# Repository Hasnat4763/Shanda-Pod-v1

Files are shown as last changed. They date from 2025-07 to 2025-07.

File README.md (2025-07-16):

# Shanda Pod

It is an MP3 player which can also play audio via bluetooth A2DP source and a PCM5102A module

I made this project because I wanted to experiment with mp3 players and I need an mp3 player with bluetooth outputs

# PCB

This is the Schematic



This is the PCB



PCB 3D View





# CAD

I designed it in Fusion360 which was pretty hard as it crashed idk why
This is all the parts fitted together







This is a cover which will sit on top of the battery



# Schematic

I have some parts outside of my PCB



# BOM

| Name | Qty | Final Price - USD(BDT) | Link |
| --- | --- | --- | --- |
| ESP-32-WROVER-E | 1 | US $7.39 | [here](https://www.aliexpress.com/item/1005008347478258.html?spm=a2g0o.cart.0.0.35b638daQUHsS4&mp=1) |
| NASAYI 10pcs/lot DM3AT-SF-PEJM5 | 10  | US $8.63 | [here](https://www.aliexpress.com/item/1005009250329013.html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) |
| CH340C sop-16 Chipset | 5 | US $1.44 | [here](https://www.aliexpress.com/item/1005004970840775.html?spm=a2g0o.cart.0.0.35b638daQUHsS4&mp=1) |
| 6092 bq25185 USB / DC / Solar Charger with 3.3V Buck Board | 1 | US $13.66 | [here](https://www.aliexpress.com/item/1005008651296534.html?spm=a2g0o.cart.0.0.35b638daQUHsS4&mp=1) |
| 100NF 0.1UF 50V C0805 Capacitor | 100 | US $0.73 | [here](https://www.aliexpress.com/item/1115774532.html?spm=a2g0o.cart.0.0.35b638daQUHsS4&mp=1) |
|  SSD1306 | 1 | US $1.42 | [here](https://www.aliexpress.com/item/1005003780343300.html?spm=a2g0o.cart.0.0.35b638daQUHsS4&mp=1) |
| PCM5102A DAC | 1 | US $4.05 | [here](https://www.aliexpress.com/item/1005006104368969.html?spm=a2g0o.cart.0.0.35b638daQUHsS4&mp=1) |
| Insert M1.6 Brass Heat Threaded Insert Nut and Stainless Steel Screw  |set  | US $15.02 | [here](https://www.aliexpress.com/item/1005004837433548.html?spm=a2g0o.cart.0.0.35b638daQUHsS4&mp=1) |
| MHP30 Mini Hot Plate | 1 | US $13.52 | [here](https://www.aliexpress.com/item/1005005887052045.html?spm=a2g0o.cart.0.0.72f938daHYVVmK&mp=1) |
| 18650 Lithium-ion | 2 | 348 BDT | [here](https://www.daraz.com.bd//products/i337388376-s1645620986.html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) |
| PCB | 5 | US $26.68 | [here](https://hc-cdn.hel1.your-objectstorage.com/s/v3/ba1be02d5d65575ba7409b266db8009ed1d59e8f_image.png) |
| Stencil | 1 | US $$8.90 | [here](https://hc-cdn.hel1.your-objectstorage.com/s/v3/ba1be02d5d65575ba7409b266db8009ed1d59e8f_image.png) | |
| Soldering Paste | 1 | US $3.81 | [here](https://www.aliexpress.com/item/1005009298760047.html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) | 
| Top Case | 1 | Printing Legion | 
| Bottom Case | 1 | Printing Legion |
| Battery Cover | 1 | Printing Legion |

# Total Cost: ~ 115$ USD

# Why is this too exbensive?

Check this out



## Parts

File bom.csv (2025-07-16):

Name | Qty | Final Price - USD(BDT) | Link
ESP-32-WROVER-E | 1 | US $7.39 | https://www.aliexpress.com/item/1005008347478258.html?spm=a2g0o.cart.0.0.35b638daQUHsS4&mp=1
NASAYI 10pcs/lot DM3AT-SF-PEJM5 | 10 | US $8.63 | https://www.aliexpress.com/item/1005009250329013.html?spm=a2g0o.cart.0.0.35b638daQUHsS4&mp=1
CH340C sop-16 Chipset | 5 | US $1.44 | https://www.aliexpress.com/item/1005004970840775.html?spm=a2g0o.cart.0.0.35b638daQUHsS4&mp=1
6092 bq25185 USB / DC / Solar Charger with 3.3V Buck Board | 1 | US $13.66 | https://www.aliexpress.com/item/1005008651296534.html?spm=a2g0o.cart.0.0.35b638daQUHsS4&mp=1
100NF 0.1UF 50V C0805 Capacitor | 100 | US $0.73 | https://www.aliexpress.com/item/1115774532.html?spm=a2g0o.cart.0.0.35b638daQUHsS4&mp=1
SSD1306 | 1 | US $1.42 | https://www.aliexpress.com/item/1005003780343300.html?spm=a2g0o.cart.0.0.35b638daQUHsS4&mp=1
PCM5102A DAC | 1 | US $4.05 | https://www.aliexpress.com/item/1005006104368969.html?spm=a2g0o.cart.0.0.35b638daQUHsS4&mp=1
Insert M1.6 Brass Heat Threaded Insert Nut and Stainless Steel Screw | set | US $15.02 | https://www.aliexpress.com/item/1005004837433548.html?spm=a2g0o.cart.0.0.35b638daQUHsS4&mp=1
MHP30 Mini Hot Plate | 1 | US $13.52 | https://www.aliexpress.com/item/1005005887052045.html?spm=a2g0o.cart.0.0.72f938daHYVVmK&mp=1
18650 Lithium-ion | 2 | 348 BDT | https://www.daraz.com.bd//products/i337388376-s1645620986.html?spm=a2o42.cart.0.0.5b8f282903B5mN
PCB | 5 | US $26.68 | https://hc-cdn.hel1.your-objectstorage.com/s/v3/ba1be02d5d65575ba7409b266db8009ed1d59e8f_image.png
Stencil | 1 | US $8.90 | https://hc-cdn.hel1.your-objectstorage.com/s/v3/ba1be02d5d65575ba7409b266db8009ed1d59e8f_image.png
Soldering Paste | 1 | US $5.66 | https://www.aliexpress.com/item/1005006866665560.html?spm=a2g0o.productlist.main.1.6cdaixN5ixN5lS
Top Case | 1 | Printing Legion
Bottom Case | 1 | Printing Legion
Battery Cover | 1 | Printing Legion
Total Cost |  | US $115.00

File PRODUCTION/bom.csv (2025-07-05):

Designator | Footprint | Quantity | Value | LCSC Part #
C1, C2, C3, C4 | 0805 | 4 | 0.1uF
J1 | microSD_HC_Hirose_DM3AT-SF-PEJM5 | 1 | Micro_SD_Card_Det2
J2 | MODULE_DM-OLED096-636 | 1 | Conn_01x04_Pin
J3 | PinHeader_1x04_P1.27mm_Vertical | 1 | Conn_01x04_Pin
J5 | PinHeader_1x05_P1.00mm_Horizontal | 1 | Conn_01x05_Socket
S1, S2, S3, S4, S5, S6 | SW_FSM8JH | 6 | FSM8JH
U1 | ESP32-WROVER-E | 1 | ESP32-WROVER-E
U3 | SOIC127P600X180-16N | 1 | CH340C

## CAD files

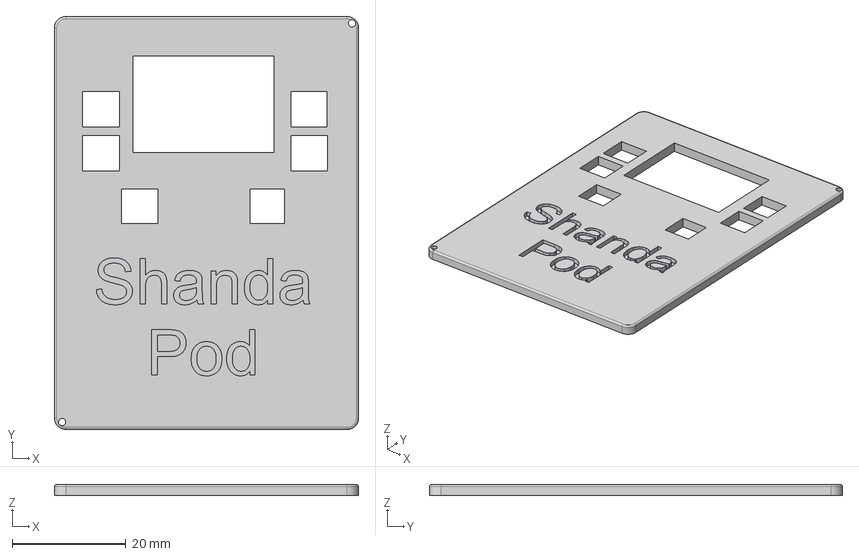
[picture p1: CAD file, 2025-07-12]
CAD/Shanda Pod Top.step
53.4 x 72.5 x 2.00 mm

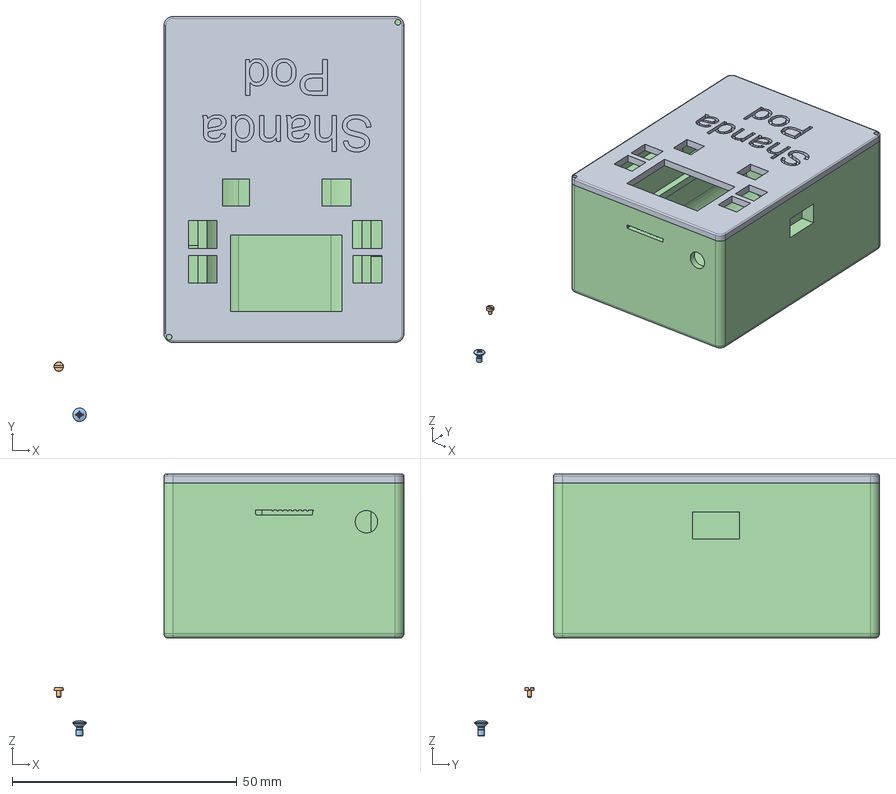
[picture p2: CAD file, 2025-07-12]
CAD/Shanda Pod Bottom.step
77.8 x 90.1 x 58.2 mm
SCHMS BS 4183 - M1 x 1.5 Steel 4.6 Plain
ČSN EN ISO 7047 - M1.6x3 - Z Steel 4.6 Plai n

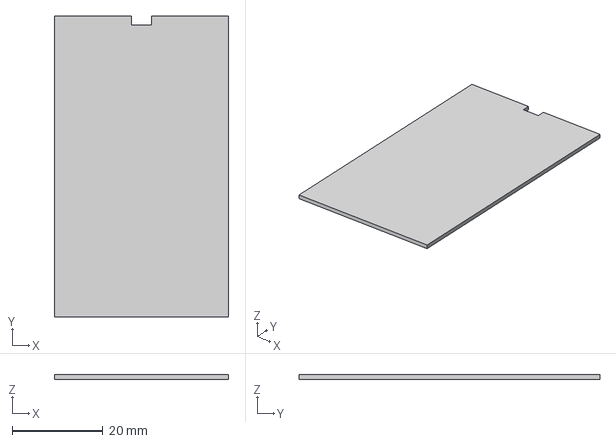
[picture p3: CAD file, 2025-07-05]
CAD/Shanda Pod Battery Cover.step
38.5 x 66.5 x 1.00 mm

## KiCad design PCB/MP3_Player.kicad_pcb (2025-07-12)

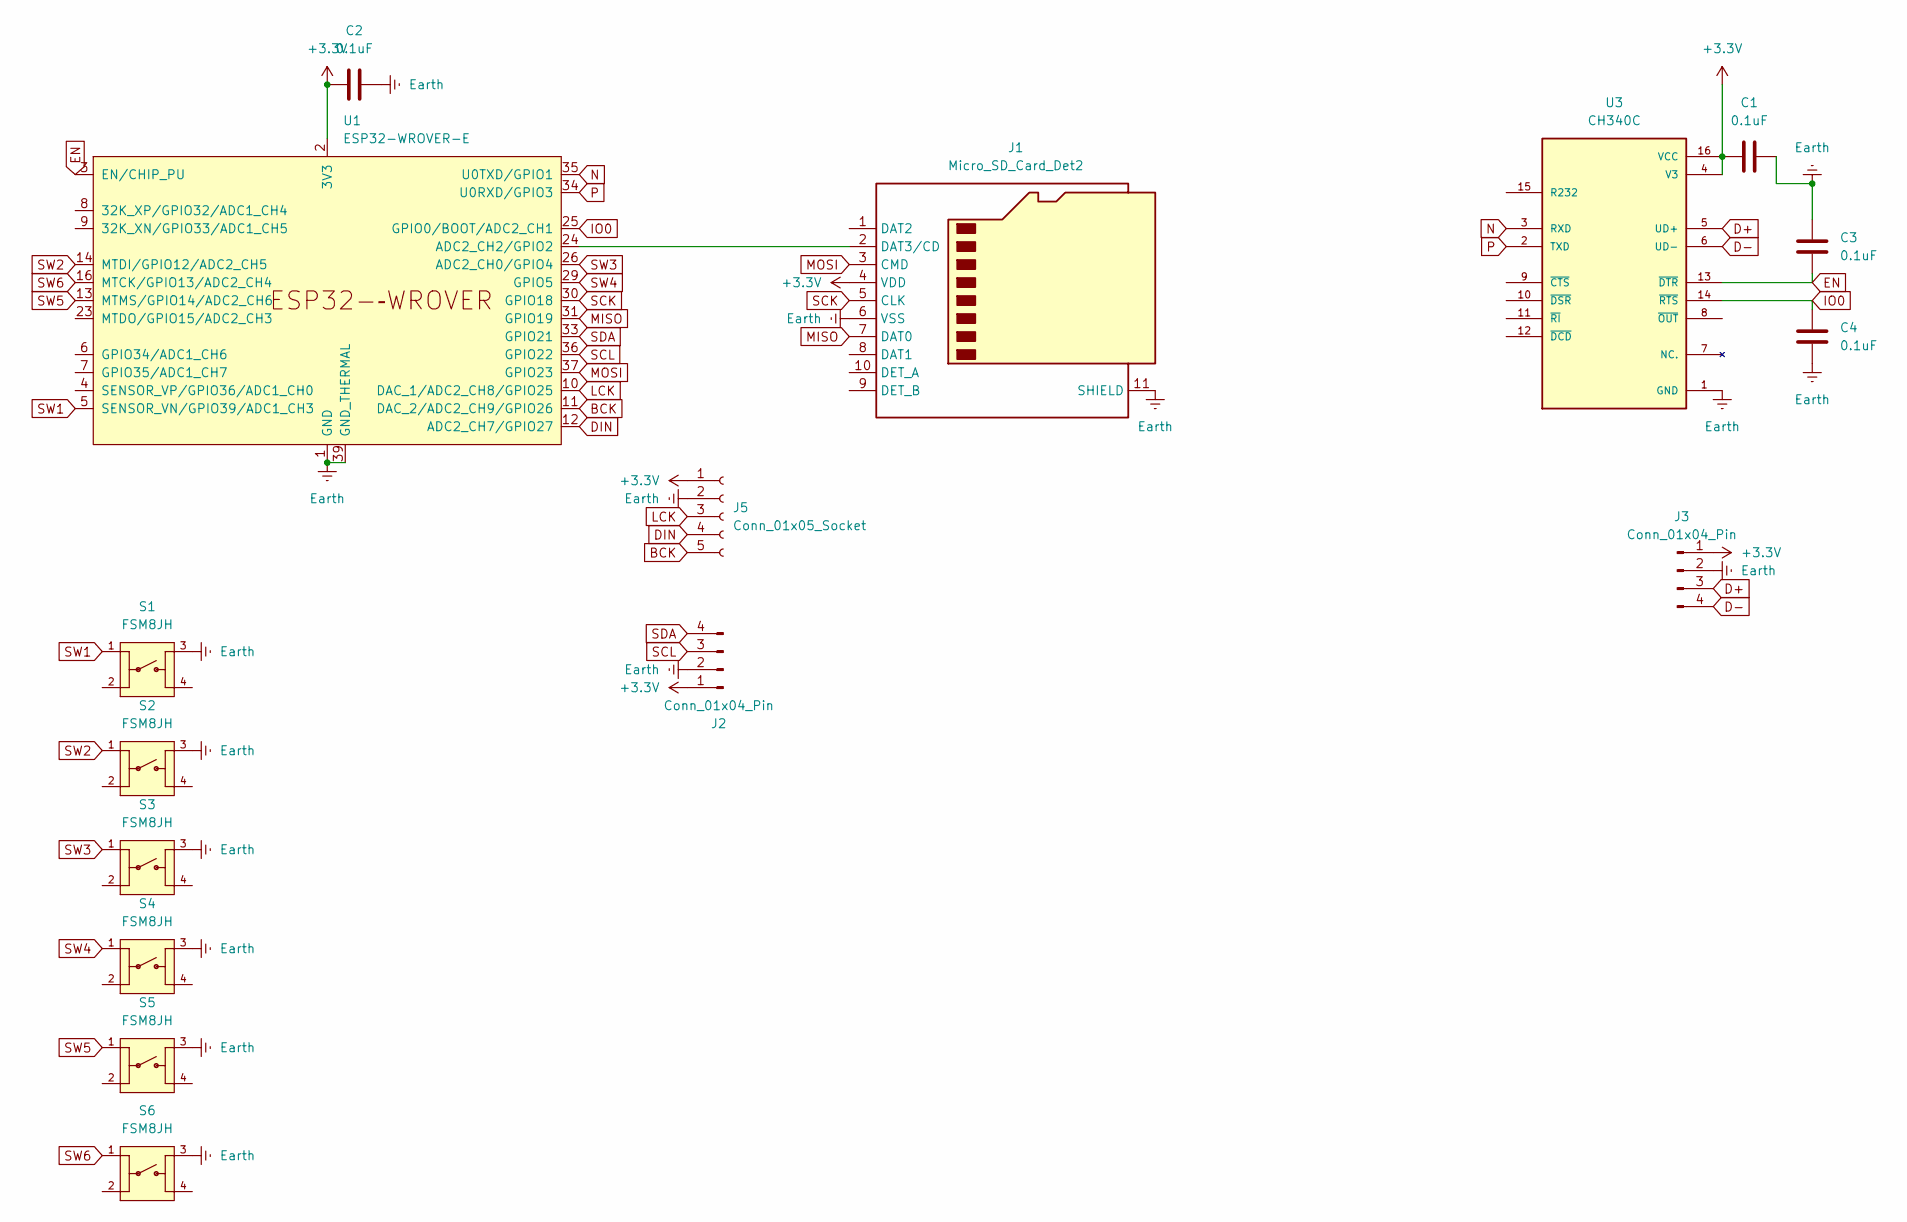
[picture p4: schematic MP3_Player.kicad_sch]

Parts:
C1, C2, C3, C4: 0.1uF; C_0805_2012Metric
J1: Micro_SD_Card_Det2; microSD_HC_Hirose_DM3AT-SF-PEJM5
J2: Conn_01x04_Pin; MODULE_DM-OLED096-636
J3: Conn_01x04_Pin; PinHeader_1x04_P1.27mm_Vertical
J5: Conn_01x05_Socket; PinHeader_1x05_P1.00mm_Horizontal
S1, S2, S3, S4, S5, S6: FSM8JH; SW_FSM8JH; PARTREV C10
U1: ESP32-WROVER-E
U3: CH340C; SOIC127P600X180-16N; PARTREV 2G

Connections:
+3.3V: C1.1, C2.1, J1.4 (VDD), J2.1, J3.1, J5.1, U1.2 (3V3), U3.4 (V3), U3.16 (VCC)
BCK: J5.5, U1.11 (DAC_2/ADC2_CH9/GPIO26)
D+: J3.3, U3.5 (UD+)
D-: J3.4, U3.6 (UD-)
DIN: J5.4, U1.12 (ADC2_CH7/GPIO27)
EN: C3.1, U1.3 (EN/CHIP_PU), U3.13 (~DTR)
Earth: C1.2, C2.2, C3.2, C4.1, J1.6 (VSS), J1.11 (SHIELD), J2.2, J3.2, J5.2, S1.3, S2.3, S3.3, S4.3, S5.3, S6.3, U1.1 (GND), U1.15 (GND), U1.38 (GND), U1.39 (GND_THERMAL), U3.1 (GND)
IO0: C4.2, U1.25 (GPIO0/BOOT/ADC2_CH1), U3.14 (~RTS)
LCK: J5.3, U1.10 (DAC_1/ADC2_CH8/GPIO25)
MISO: J1.7 (DAT0), U1.31 (GPIO19)
MOSI: J1.3 (CMD), U1.37 (GPIO23)
N: U1.35 (U0TXD/GPIO1), U3.3 (RXD)
unnamed: J1.2 (DAT3/CD), U1.24 (ADC2_CH2/GPIO2)
P: U1.34 (U0RXD/GPIO3), U3.2 (TXD)
SCK: J1.5 (CLK), U1.30 (GPIO18)
SCL: J2.3, U1.36 (GPIO22)
SDA: J2.4, U1.33 (GPIO21)
SW1: S1.1, U1.5 (SENSOR_VN/GPIO39/ADC1_CH3)
SW2: S2.1, U1.14 (MTDI/GPIO12/ADC2_CH5)
SW3: S3.1, U1.26 (ADC2_CH0/GPIO4)
SW4: S4.1, U1.29 (GPIO5)
SW5: S5.1, U1.13 (MTMS/GPIO14/ADC2_CH6)
SW6: S6.1, U1.16 (MTCK/GPIO13/ADC2_CH4)

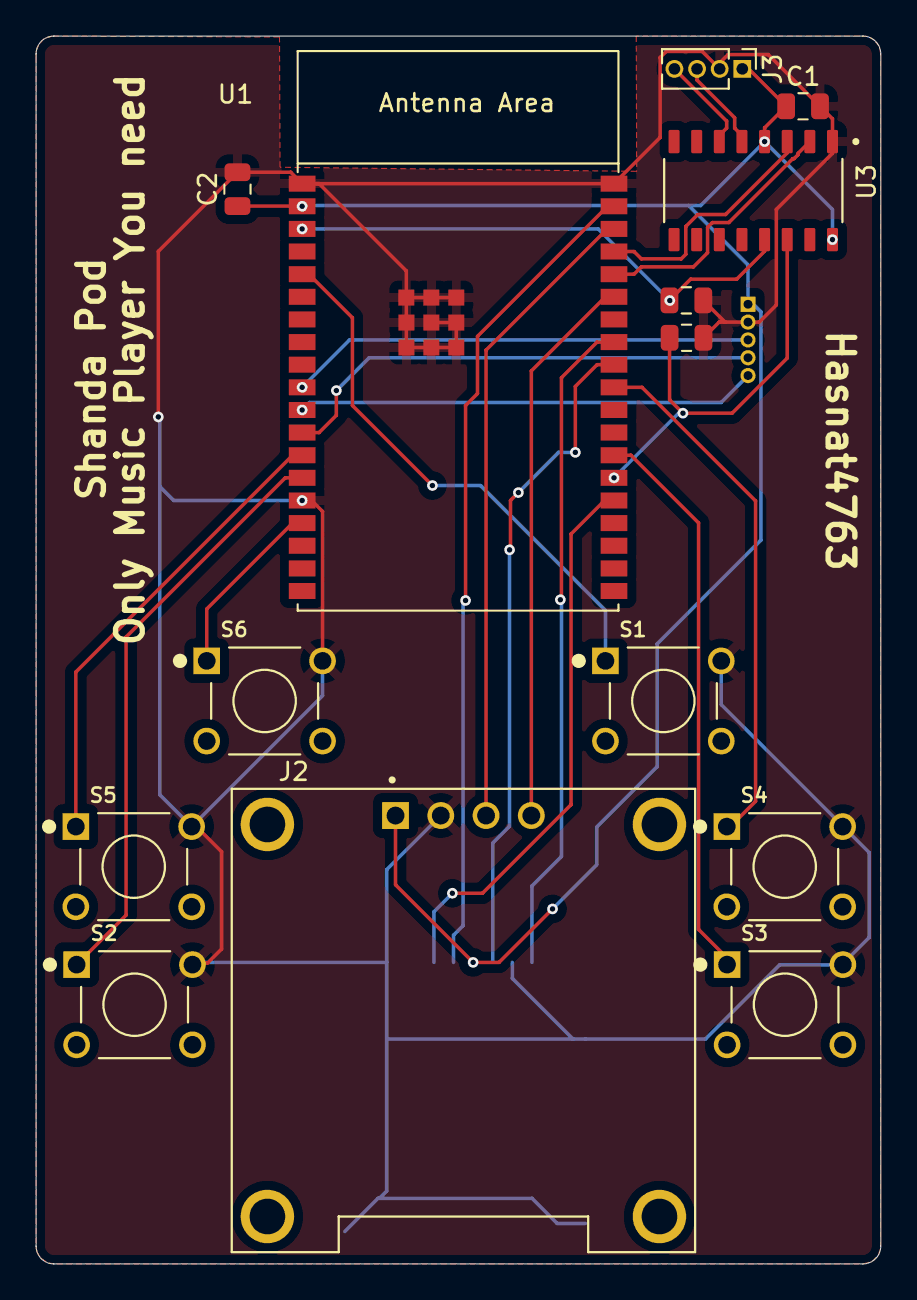
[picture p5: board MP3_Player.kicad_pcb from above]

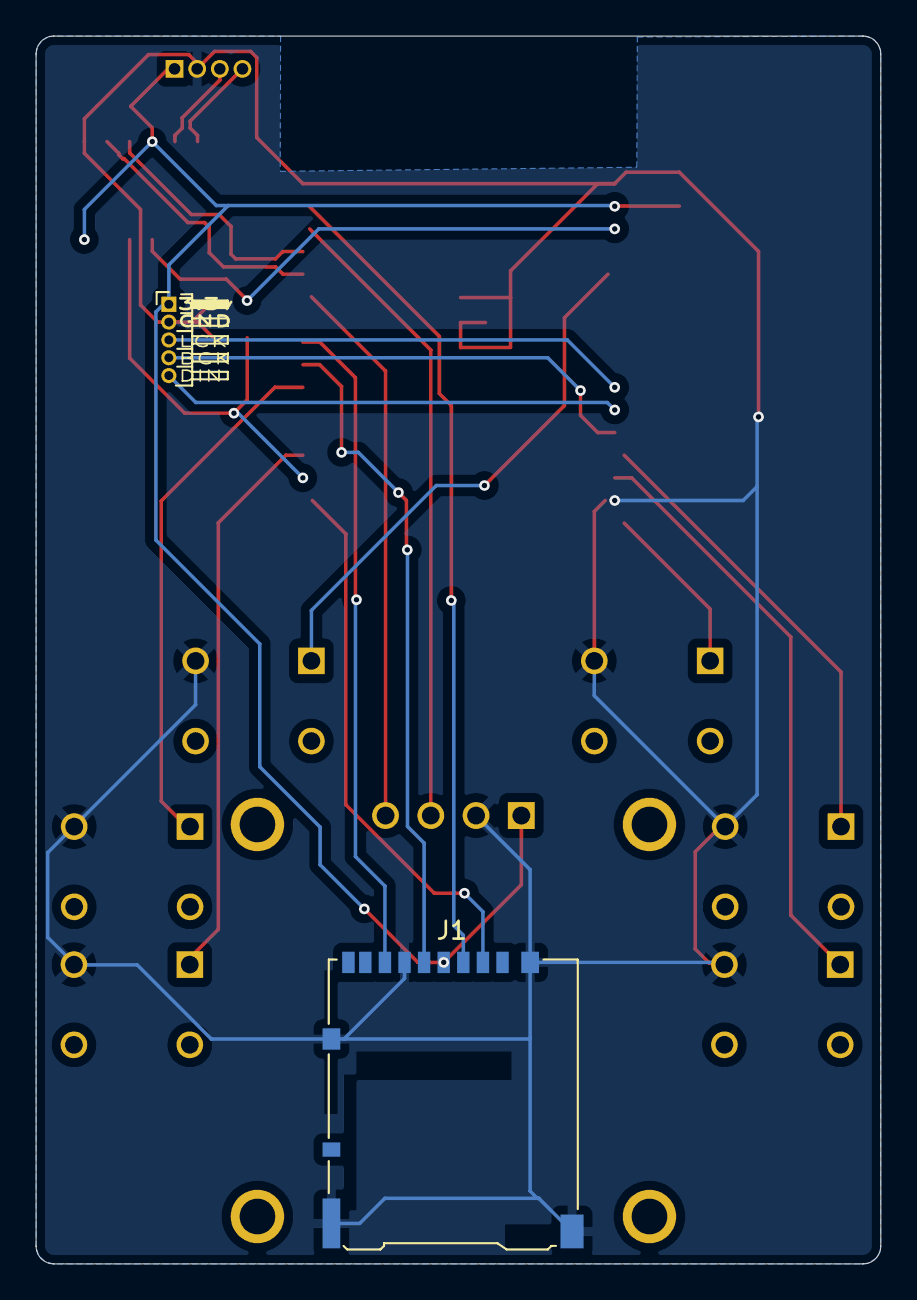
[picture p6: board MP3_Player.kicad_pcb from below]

Board: 2 copper layers, 47.4 x 68.9 mm, 16 parts (2 on the bottom side), 23 nets.

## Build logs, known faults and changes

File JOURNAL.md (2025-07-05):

---
title: "Shanda Pod"
author: "Hasnat"
description: "It is an MP3 player!"
created_at: "2025-06-05"
---

# Total Time Spent: 20.5h

# June 5th: Started Making the base

I have started working on an MP3 player which will also be able to output audio to my Airbuds.

I have selected the ESP32 WROVER as the MCU.

Put an OLED display and SD card reader to it too.





Not sure about them tho still a lot to do

**Total time spent: 3hr**

# June 8th: Edited the schematic a bit

I never used a microSD card with any microcontroller before so I was confused as how to wire the pins to my ESP32. I finally figured it out and wired them up. I also added 4 male jumper pins so that I can easily use a USB to 

TTL converter or my arduino nano to flash new codes on the ESP32.





PCB looks like this now

**Total time spent: 1hr**

# June 9th: Added voltage converter

The ESP32 runs on 3.3v but most of the batteries we find like the 18650 li-ion batteries all have a voltage range of 3.7-4.2 which is not safe for the ESP32 so I desided to include a AMS1117 LDO to limit the voltage to 3.3v. I also put a JST connector to connect the battery to the PCB.





**Total time spent: 2hr**

# June 11th: Added extra switch and tidied up the schematic

Thought I need some more switches for the MP3 player. So added 2 more switches.

Gonna start working on the case now.





**Total time spent: 0.5hr**

# June 13th: Changed switch model and added voltage reading

I want to also see how much charge is left on the battery, so I added 2 resistors to step down the voltage which esp32 can read safely
Also Changed the switch models







**Total time spent: 0.5hr**

# June 18th: Finalizing the case

Got some free time today to become Good in CAD. I still have to figure out where to put the battery tho





**Total time spent: 1.5hr**

# June 20th: Big Changes

I have decided to also include a GY-PCM5102 module for audio output so I have to change many things. I have also changed the case design to be more compact
Placed the Charging and Audio out Module till now
Have to put the power button now

Also Changed the PCB





**Total time spent: 2hr**

# June 21th: Big Changes

Changed the Battery Charging module for an adafruit bq25185 charging module as it has both charging and 3v3 output. Removed AMS1117 and battery percentage function from the PCB
Made space for the new module in Case.





**Total time spent: 2.5hr**

# June 23th: WHY AM I DOING THIS?

I have exams tomorrow and yet I am making the case
I completed the case (Looks Like I am gonna change it again ngl) and made an exploding animation of it!

https://github.com/user-attachments/assets/a201ade8-0bba-4978-ab63-54ee87a1c3f5

**Total time spent: 1.5hr**

# June 26th: Adding CH340C

Thought of including an CH340C USB to UART converter to upload codes easily and also my battery charger also exposes D+ D- so it is easier than ever







**Total time spent: 2hr**

# June 27th: Completely changing the case design and choosing battery

I had completely redone the case and selected 2 18650 batteries to power it and added a rocker switch to turn on/off

(Hope everything fits)



**Total time spent: 3hr**

# July 1st: Adding screw holes and switch

I made holes for 2 M1.6 screws and made hole for a slide switch




**Total time spent: 1hr**

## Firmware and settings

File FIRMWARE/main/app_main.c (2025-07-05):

#include <stdio.h>
#include <dirent.h>
#include <string.h>
#include "freertos/FreeRTOS.h"
#include "freertos/task.h"
#include "driver/gpio.h"
#include "esp_log.h"
#include "esp_err.h"
#include "audio_element.h"
#include "audio_pipeline.h"
#include "audio_event_iface.h"
#include "esp_vfs_fat.h"
#include "sdmmc_cmd.h"
#include "i2s_stream.h"
#include "fatfs_stream.h"
#include "mp3_decoder.h"
#include "esp_peripherals.h"
#include "periph_sdcard.h"
#include "board.h"

static const char *TAG = "MP3_PLAYER";

#define MOUNT_POINT "/sdcard"


#define BUTTON_NEXT        GPIO_NUM_32
#define BUTTON_PREV        GPIO_NUM_33
#define BUTTON_PLAY_PAUSE  GPIO_NUM_25
#define BUTTON_VOL_UP      GPIO_NUM_26
#define BUTTON_VOL_DOWN    GPIO_NUM_27
#define BUTTON_BL_CONTROL  GPIO_NUM_14

#define MAX_FILES 64
static char file_list[MAX_FILES][256];
static int total_files = 0;
static int current_index = 0;
static bool is_playing = true;
static audio_pipeline_handle_t pipeline = NULL;
static audio_element_handle_t i2s_stream_writer = NULL;

void play_file(const char *filepath)
{
    ESP_LOGI(TAG, "Playing file: %s", filepath);

    if (pipeline) {
        audio_pipeline_terminate(pipeline);
        audio_pipeline_deinit(pipeline);
        pipeline = NULL;
    }

    audio_element_handle_t fatfs_stream_reader, mp3_decoder;

    audio_pipeline_cfg_t pipeline_cfg = DEFAULT_AUDIO_PIPELINE_CONFIG();
    pipeline = audio_pipeline_init(&pipeline_cfg);
    mem_assert(pipeline);

    fatfs_stream_cfg_t fatfs_cfg = FATFS_STREAM_CFG_DEFAULT();
    fatfs_cfg.type = AUDIO_STREAM_READER;
    fatfs_stream_reader = fatfs_stream_init(&fatfs_cfg);

    mp3_decoder_cfg_t mp3_cfg = DEFAULT_MP3_DECODER_CONFIG();
    mp3_decoder = mp3_decoder_init(&mp3_cfg);

    i2s_stream_cfg_t i2s_cfg = I2S_STREAM_CFG_DEFAULT();
    i2s_cfg.type = AUDIO_STREAM_WRITER;
    i2s_stream_writer = i2s_stream_init(&i2s_cfg);

    audio_pipeline_register(pipeline, fatfs_stream_reader, "file");
    audio_pipeline_register(pipeline, mp3_decoder, "mp3");
    audio_pipeline_register(pipeline, i2s_stream_writer, "i2s");

    audio_pipeline_link(pipeline, (const char *[]) {"file", "mp3", "i2s"}, 3);

    audio_element_set_uri(fatfs_stream_reader, filepath);

    audio_pipeline_run(pipeline);
    is_playing = true;
}

void configure_buttons()
{
    gpio_config_t io_conf = {
        .intr_type = GPIO_INTR_DISABLE,
        .mode = GPIO_MODE_INPUT,
        .pull_up_en = GPIO_PULLUP_ENABLE,
        .pull_down_en = GPIO_PULLDOWN_DISABLE,
        .pin_bit_mask = (1ULL << BUTTON_NEXT) | (1ULL << BUTTON_PREV) |
                        (1ULL << BUTTON_PLAY_PAUSE) | (1ULL << BUTTON_VOL_UP) |
                        (1ULL << BUTTON_VOL_DOWN) | (1ULL << BUTTON_BL_CONTROL)
    };
    gpio_config(&io_conf);
}

void button_poll_task(void *arg)
{
    bool last_next = true, last_prev = true, last_play = true;
    bool last_vol_up = true, last_vol_down = true;

    while (1) {
        bool curr_next = gpio_get_level(BUTTON_NEXT);
        bool curr_prev = gpio_get_level(BUTTON_PREV);
        bool curr_play = gpio_get_level(BUTTON_PLAY_PAUSE);
        bool curr_vol_up = gpio_get_level(BUTTON_VOL_UP);
        bool curr_vol_down = gpio_get_level(BUTTON_VOL_DOWN);

        if (!curr_next && last_next) {
            current_index = (current_index + 1) % total_files;
            play_file(file_list[current_index]);
        }
        if (!curr_prev && last_prev) {
            current_index = (current_index - 1 + total_files) % total_files;
            play_file(file_list[current_index]);
        }
        if (!curr_play && last_play) {
            if (is_playing) {
                audio_pipeline_pause(pipeline);
                is_playing = false;
            } else {
                audio_pipeline_resume(pipeline);
                is_playing = true;
            }
        }
        if (!curr_vol_up && last_vol_up) {
            audio_element_info_t info = {};
            audio_element_getinfo(i2s_stream_writer, &info);
            info.volume += 10;
            if (info.volume > 100) info.volume = 100;
            audio_element_setinfo(i2s_stream_writer, &info);
        }
        if (!curr_vol_down && last_vol_down) {
            audio_element_info_t info = {};
            audio_element_getinfo(i2s_stream_writer, &info);
            info.volume -= 10;
            if (info.volume < 0) info.volume = 0;
            audio_element_setinfo(i2s_stream_writer, &info);
        }

        last_next = curr_next;
        last_prev = curr_prev;
        last_play = curr_play;
        last_vol_up = curr_vol_up;
        last_vol_down = curr_vol_down;

        vTaskDelay(pdMS_TO_TICKS(150));
    }
}

void app_main(void)
{
    esp_log_level_set("AUDIO_ELEMENT", ESP_LOG_WARN);

    ESP_LOGI(TAG, "Initializing peripherals...");
    esp_periph_config_t periph_cfg = DEFAULT_ESP_PERIPH_SET_CONFIG();
    esp_periph_set_handle_t set = esp_periph_set_init(&periph_cfg);

    audio_board_sdcard_init(set, ESP_SD_MODE_SPI);
    configure_buttons();

    ESP_LOGI(TAG, "Opening directory %s", MOUNT_POINT);
    DIR *dir = opendir(MOUNT_POINT);
    if (!dir) {
        ESP_LOGE(TAG, "Failed to open dir: %s", MOUNT_POINT);
        return;
    }

    struct dirent *entry;
    while ((entry = readdir(dir)) != NULL && total_files < MAX_FILES) {
        if (entry->d_type == DT_REG && strstr(entry->d_name, ".mp3")) {
            snprintf(file_list[total_files], sizeof(file_list[0]), "%s/%s", MOUNT_POINT, entry->d_name);
            total_files++;
        }
    }
    closedir(dir);

    if (total_files == 0) {
        ESP_LOGW(TAG, "No MP3 files found");
        return;
    }

    current_index = 0;
    play_file(file_list[current_index]);

    xTaskCreate(button_poll_task, "button_poll", 4096, NULL, 5, NULL);

    while (1) {
        vTaskDelay(pdMS_TO_TICKS(1000));
    }
